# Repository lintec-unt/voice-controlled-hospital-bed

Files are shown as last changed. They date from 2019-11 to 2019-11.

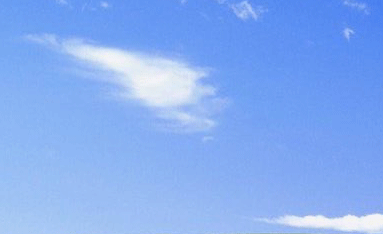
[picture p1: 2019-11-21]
PCSoftwareCode/Resources/FondoModificado_04.gif

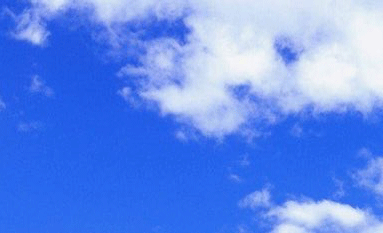
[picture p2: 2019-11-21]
PCSoftwareCode/Resources/FondoModificado_031.gif

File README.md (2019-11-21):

# Voice Controlled Hospital Bed System 1.0

This is the version 1.0 of the Voice Controlled Hospital Bed System. This proyect aims to allow bedridden patients that have a discapacity that do not allow them to use their hands to control the position of their bed, but they can talk, to control the bed with oral commands.

In this first version, the system can only work with a particular model of hospital bed (Pettinari PM Millennium), and it works with a PC with a speech recognition software (for example, Windows Speech Recognition, Dragon NaturallySpeaking, among others).

The system has the following parts:

* PC with Microsoft Windows OS and a speech recognition software.
* PC software to control the hospital bed.
* Arduino UNO board that translates the commands from the PC to actions in the bed.
* An Arduino shield that has all the extra hardware needed.
* A case to put the Arduino board and its shield to adapt it in the bed.

In this repository, we have uploaded the codes and files of:

* Code of the PC software to control the hospital bed.
* Code of the Arduino UNO board.
* PCB design of the Arduino shield.
* A STL file of the case.

### Arduino shield (PCB folder)

The arduino UNO board is connected to the hospital bed by the communication port for the wired remote control command. To emulate the buttons of the remote control, we used the GPIO port. As we intended to avoid electrical connection between the Arduino board (and the PC in upstream connection), the connections with the bed and the GPIO ports are between optocouplers. After the optocouplers, there is DIN connector (DIN 41524) that is connected in the bed. the connection between the PC and the Arduino board is by the means of the USB serial port.

The PCB design (the PCB folder) includes the optocouplers and a connector for the cable with the DIN connection.

### Arduino Board Software (ArduinoCode folder)

It was developed under Arduino IDE and with the standard libraries from Arduino.cc

This software has the typical infinite loop structure (setup() and loop()). In setup(), it starts all the GPIO pin needed as inputs and wait a command from the PC to start working. In loop(), the Arduino receive a char, and if it means a valid command, it activates the corresponding GPIO pin.

### The case (STL folder)

The arduino board and its shield was attached in the hospital bed by a 3d printed case. This case works as kind of protection for all the electronics.  

### The PC sofware (PCSoftwareCode folder)

The software that send the commands to the arduino is coded in C#, it was coded under Visual Studio IDE 15.

When the software is initializated, it search for the Arduino board in the differents avalaible serial ports (COM ports). To find it, it sends a char that the Arduino undestand as valid one and the Arduino responds with another char. The main windows has all the commands to move the bed in the form of images. If the user does a click in one of them, the software sends the correponding command to the Arduino to move the bed every 500 ms (this delta of time assures a smooth movement of the bed). To stop the movement, it is necesary to click in the same image but also, the software automatically stop the movement after 30 seconds.

The user using the speech recognition software can send a voice command to make click in one of the images. The size of the images are intended to make easier to the user to choose one of the images.

## Roadmap

For new advances in this work, we want to add the support for other models and brand of hospital beds. Also, we want adding the posibility to replace the PC with a embebbed system with a buit-in speech recognition software.

We are open to new ideas, everyone is open to participate in this development, as long as the guidelines are respected (see Contributing.md)

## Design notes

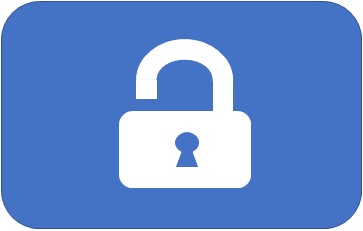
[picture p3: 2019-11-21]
PCSoftwareCode/Resources/az_desbloq.jpg

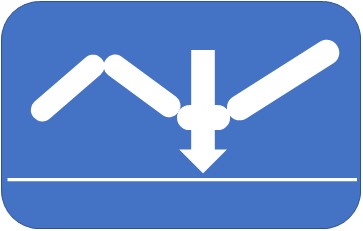
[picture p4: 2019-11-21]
PCSoftwareCode/Resources/az_cm_aba1.JPG

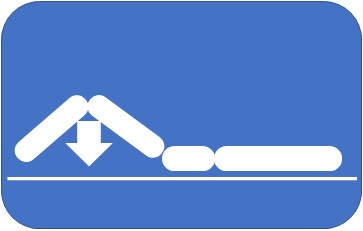
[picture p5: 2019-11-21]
PCSoftwareCode/Resources/az_pie_aba1.JPG

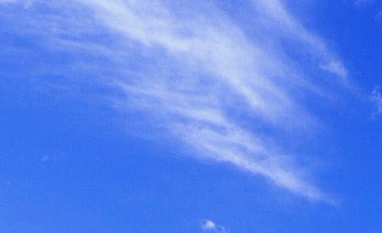
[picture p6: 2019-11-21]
PCSoftwareCode/Resources/FondoModificado_02.gif

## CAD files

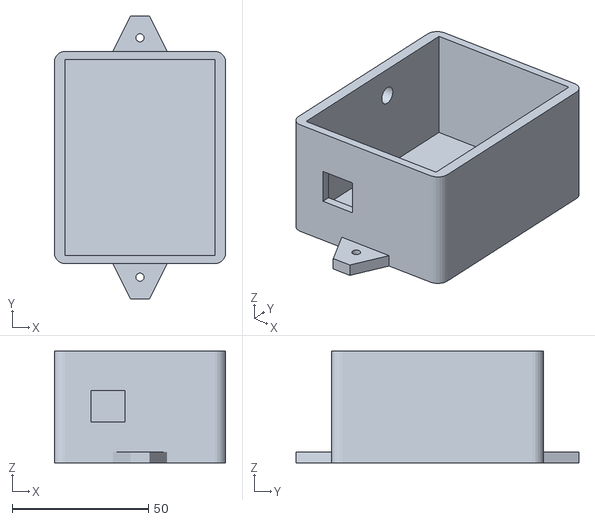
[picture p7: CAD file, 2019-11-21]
STLCase/ArduinoCase.stl
63.0 x 104.0 x 41.0

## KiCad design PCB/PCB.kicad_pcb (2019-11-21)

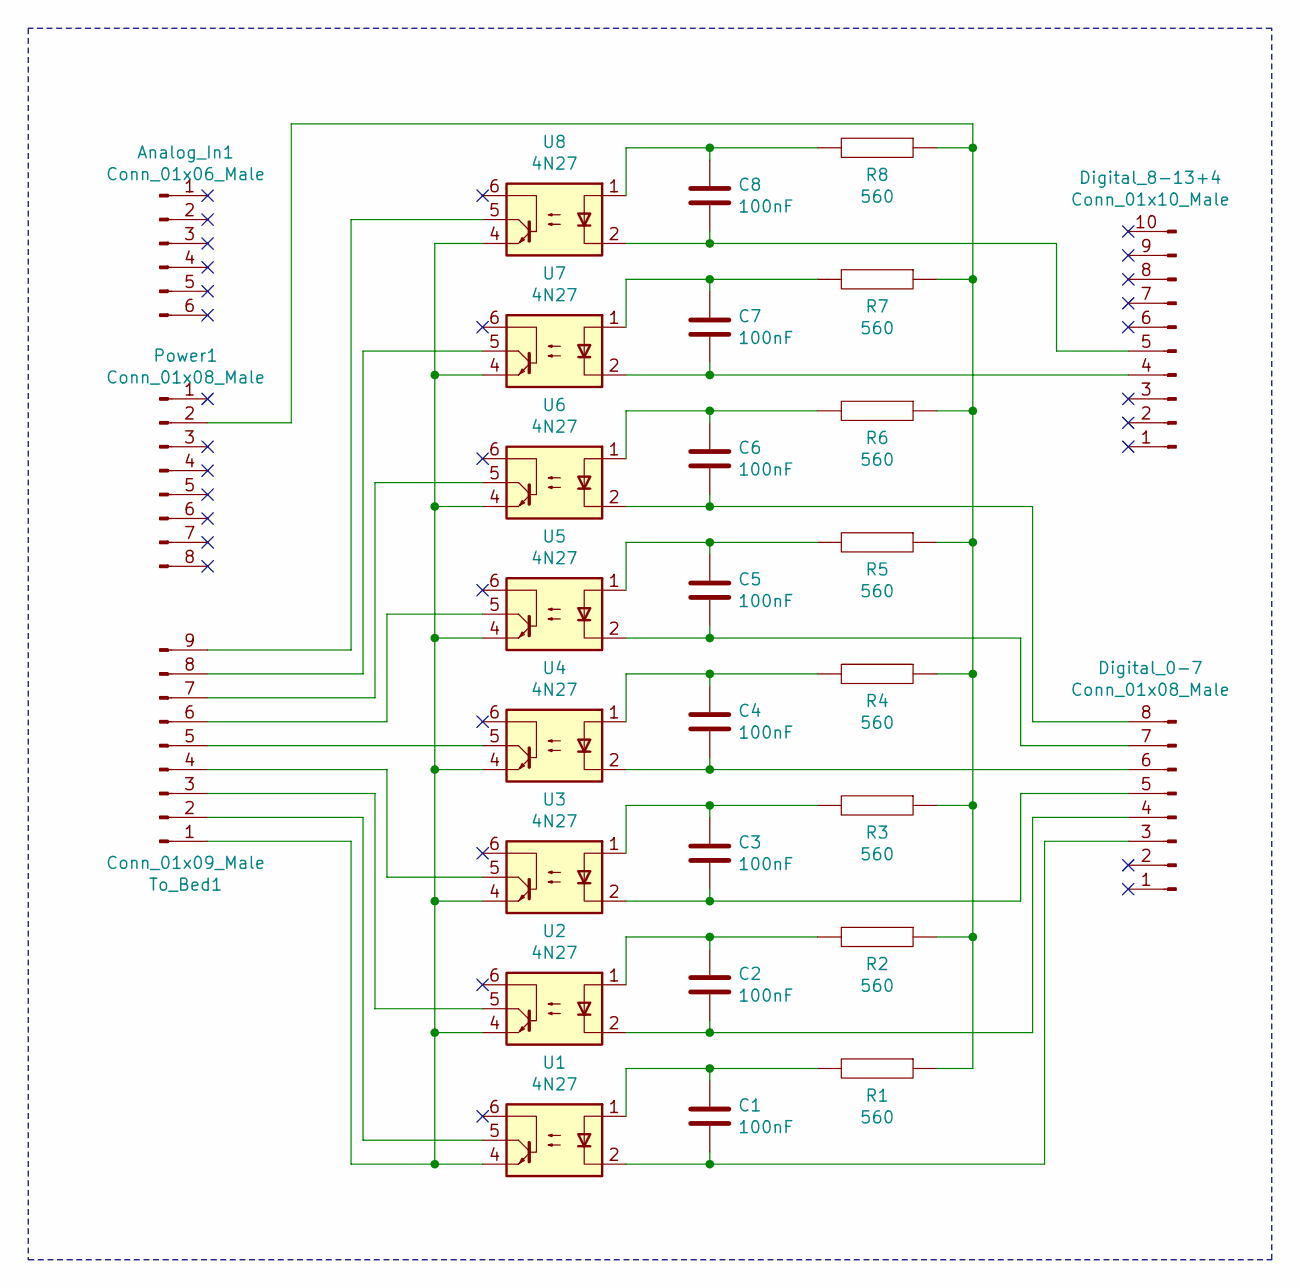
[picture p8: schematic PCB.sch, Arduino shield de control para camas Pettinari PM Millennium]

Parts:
Analog_In1: Conn_01x06_Male; PinHeader_1x06_P2.54mm_Vertical
C1, C2, C3, C4, C5, C6, C7, C8: 100nF; C_Disc_D6.0mm_W2.5mm_P5.00mm
Digital_0-7: Conn_01x08_Male; PinHeader_1x08_P2.54mm_Vertical
Digital_8-13+4: Conn_01x10_Male; PinHeader_1x10_P2.54mm_Vertical
Power1: Conn_01x08_Male; PinHeader_1x08_P2.54mm_Vertical
R1, R2, R3, R4, R5, R6, R7, R8: 560; R_Axial_DIN0207_L6.3mm_D2.5mm_P7.62mm_Horizontal
To_Bed1: Conn_01x09_Male; PinHeader_1x09_P2.54mm_Vertical
U1, U2, U3, U4, U5, U6, U7, U8: 4N27; DIP-6_W7.62mm

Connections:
unnamed: C1.1, R1.2, U1.1
unnamed: C1.2, Digital_0-7.3, U1.2
unnamed: C2.1, R2.2, U2.1
unnamed: C2.2, Digital_0-7.4, U2.2
unnamed: C3.1, R3.2, U3.1
unnamed: C3.2, Digital_0-7.5, U3.2
unnamed: C4.1, R4.2, U4.1
unnamed: C4.2, Digital_0-7.6, U4.2
unnamed: C5.1, R5.2, U5.1
unnamed: C5.2, Digital_0-7.7, U5.2
unnamed: C6.1, R6.2, U6.1
unnamed: C6.2, Digital_0-7.8, U6.2
unnamed: C7.1, R7.2, U7.1
unnamed: C7.2, Digital_8-13+4.4, U7.2
unnamed: C8.1, R8.2, U8.1
unnamed: C8.2, Digital_8-13+4.5, U8.2
unnamed: Power1.2, R1.1, R2.1, R3.1, R4.1, R5.1, R6.1, R7.1, R8.1
unnamed: To_Bed1.1, U1.4, U2.4, U3.4, U4.4, U5.4, U6.4, U7.4, U8.4
unnamed: To_Bed1.2, U1.5
unnamed: To_Bed1.3, U2.5
unnamed: To_Bed1.4, U3.5
unnamed: To_Bed1.5, U4.5
unnamed: To_Bed1.6, U5.5
unnamed: To_Bed1.7, U6.5
unnamed: To_Bed1.8, U7.5
unnamed: To_Bed1.9, U8.5

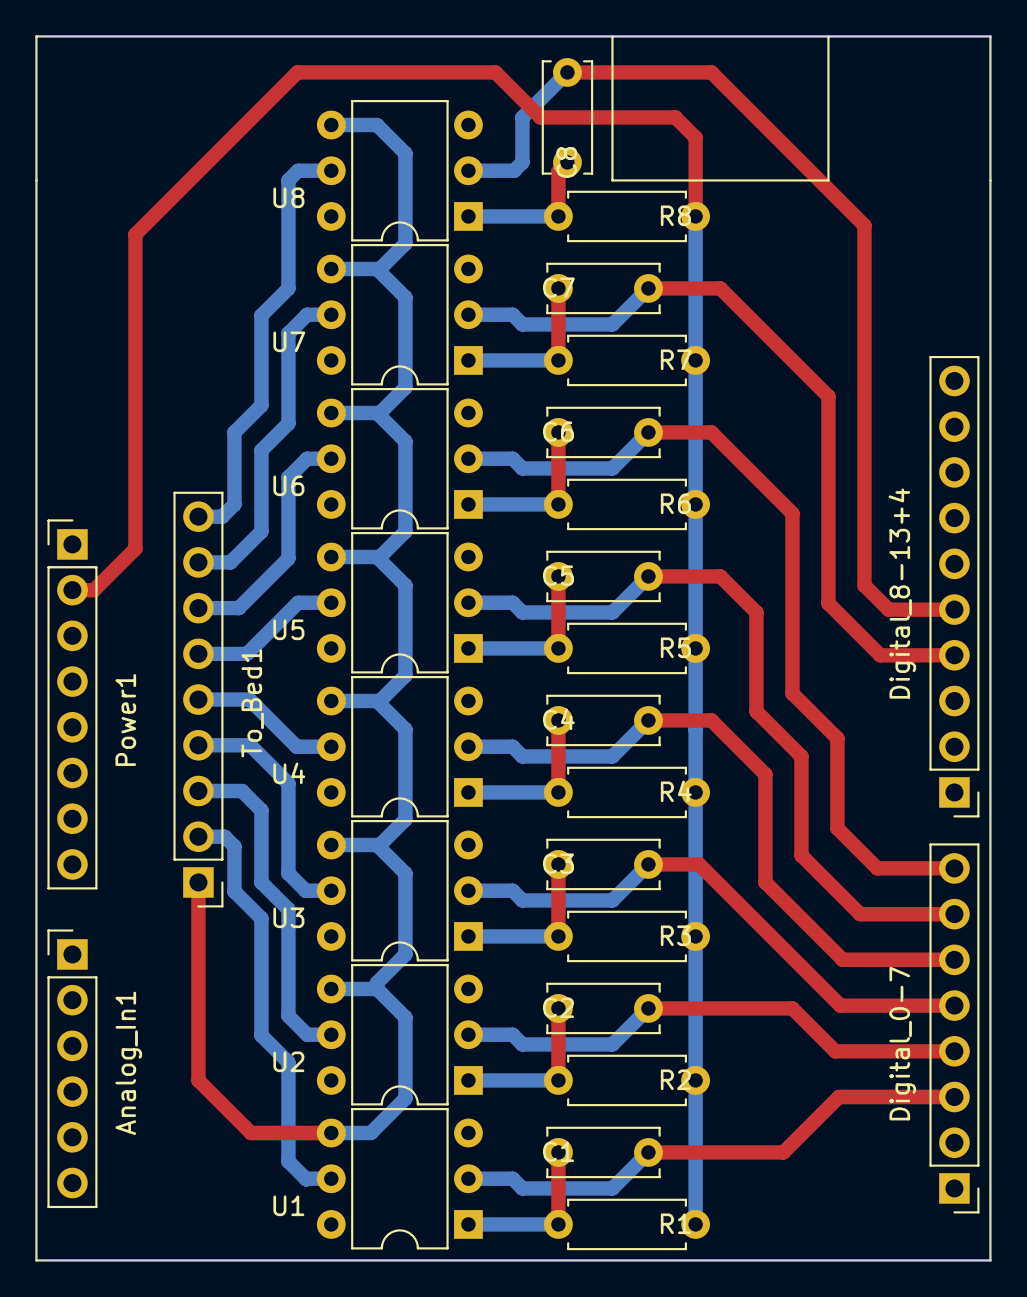
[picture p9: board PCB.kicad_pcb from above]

Board: 2 copper layers, 53.0 x 68.0 mm, 29 parts (0 on the bottom side), 26 nets.

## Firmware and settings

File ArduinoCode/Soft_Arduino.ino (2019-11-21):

/* Copyright (c) 2019, CONICET, UNT, SIPROSA
 * All rights reserved.
 *
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
 *
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
 *
 * 3. Neither the name of the copyright holder nor the names of its
 *    contributors may be used to endorse or promote products derived from
 *    this software without specific prior written permission.
 *
 *
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
 */

/* Author: Facundo Adrián Lucianna (flucianna@herrera.unt.edu.ar) */
/* Date (DD/MM/YYYY): 11/10/2018 */

/*==================[macros y definiciones]=================================*/

#define NPIN1  2     //Pin 2 Arduino
#define NPIN2  3     //Pin 3 Arduino
#define NPIN3  4     //Pin 4 Arduino
#define NPIN4  5     //Pin 5 Arduino
#define NPIN5  6     //Pin 6 Arduino
#define NPIN6  7     //Pin 7 Arduino
#define NPIN7  11    //Pin 11 Arduino
#define NPIN8  12    //Pin 12 Arduino

#define SERIALOKPC          99      //El caracter "c" en ASCII que envia la PC para conectar con el sistema
#define SERIALACKTOPC       10      //Se envia el numero 10 a la PC para avisarle que esta vivo.

#define SERIALPENADEL       51      //ASCII para pendulo adelante
#define SERIALPENATRAS      49      //ASCII para pendulo atras

#define SERIALPIEARRIBA     56      //ASCII para pie arriba
#define SERIALPIEABAJO      50      //ASCII para pie arriba

#define SERIALCABABAJO      52      //ASCII para cabeza abajo
#define SERIALCABARRIBA     55      //ASCII para cabeza arriba

#define SERIALCAMAABAJO     53      //ASCII para cama abajo
#define SERIALCAMAARRIBA    54      //ASCII para cama arriba

#define SERIALDESBLOQUEO    57      //Serial para desbloqueo

#define TIEMPOESPERACONF    250     //1/4 de segundo de espera
#define TIEMPOESPERASERIAL  500     //Medio segundo de espera
#define BAUDS               9600    //9600 baudios de transmision serial

/*==================[tipos de datos declarados por el usuario]===============*/
/*==================[declaraciones de datos externos]========================*/

int incomingByte = 0; // Variable que almacena lo que llega de la PC

bool flagSerial = false; // Flag para indicar que llego algo del puerto serie

/*==================[definiciones de funciones externas]=====================*/

/*-----------------------------------------------------------------
 *   La función setup() configura las salidas de los pines para
 *   controlar la cama y luego se configura el puerto serie y espera
 *   a la PC o sistema embebido que lo controla se comunique con el
 *   sistema.
 *-----------------------------------------------------------------*/
void setup()
{

  pinMode(NPIN1,OUTPUT);
  pinMode(NPIN2,OUTPUT);
  pinMode(NPIN3,OUTPUT);
  pinMode(NPIN4,OUTPUT);
  pinMode(NPIN5,OUTPUT);
  pinMode(NPIN6,OUTPUT);
  pinMode(NPIN7,OUTPUT);
  pinMode(NPIN8,OUTPUT);

  digitalWrite(NPIN1, HIGH);
  digitalWrite(NPIN2, HIGH);
  digitalWrite(NPIN3, HIGH);
  digitalWrite(NPIN4, HIGH);
  digitalWrite(NPIN5, HIGH);
  digitalWrite(NPIN6, HIGH);
  digitalWrite(NPIN7, HIGH);
  digitalWrite(NPIN8, HIGH);

  delay(TIEMPOESPERACONF);

  Serial.begin(BAUDS);
  //Serial.println("Test cama");   // DEBUG: Mensaje de bienvenida

  delay(TIEMPOESPERACONF);

  while(1) {
    if (Serial.available() > 0) { // Hay algo en el puerto serie

      incomingByte = Serial.read(); // Leemos el dato

      if (incomingByte == SERIALOKPC) {  // La PC intenta conectarse al Arduino

        Serial.print(SERIALACKTOPC, DEC);   // Confirmamos intento de conexión al software
        break;

      }
    }
  }
}

/*-----------------------------------------------------------------
 *   La función loop() realiza el bucle infinito en donde se recibe
 *   los caracteres de la PC y en funcion de cual sea, da un control
 *   a la cama.
 *-----------------------------------------------------------------*/
void loop()
{

  if (Serial.available() > 0) { // Hay algo en el puerto serie

    incomingByte = Serial.read(); // Leemos el dato

    //Esto es necesario si la PC se desconecta y vuelve a conectar y no se tenga que reiniciar el microcontrolador.
    if (incomingByte == SERIALOKPC) { // El software intenta conectarse al Arduino

      Serial.print(SERIALACKTOPC,DEC);// Confirmamos intento de conexión al software
      flagSerial = false;
    } else {

      flagSerial = true;
    }
  }

  if (flagSerial) {   // Esta flag esta para que solo cambie de estado los pines cuando se recibio algo del puerto serial.

    switch (incomingByte) {  // Dependiendo del valor de la variable, hacemos algo o no.
      case SERIALPENADEL:

        digitalWrite(NPIN1, LOW);
        digitalWrite(NPIN2,HIGH);
        digitalWrite(NPIN3,HIGH);
        digitalWrite(NPIN4,HIGH);
        digitalWrite(NPIN5,HIGH);
        digitalWrite(NPIN6,HIGH);
        digitalWrite(NPIN7,HIGH);
        digitalWrite(NPIN8,HIGH);
        flagSerial = false;
        break;
      case SERIALPIEABAJO:

        digitalWrite(NPIN1,HIGH);
        digitalWrite(NPIN2,LOW);
        digitalWrite(NPIN3,HIGH);
        digitalWrite(NPIN4,HIGH);
        digitalWrite(NPIN5,HIGH);
        digitalWrite(NPIN6,HIGH);
        digitalWrite(NPIN7,HIGH);
        digitalWrite(NPIN8,HIGH);

        flagSerial = false;
        break;
     case SERIALCABABAJO:

        digitalWrite(NPIN1,HIGH);
        digitalWrite(NPIN2,HIGH);
        digitalWrite(NPIN3,LOW);
        digitalWrite(NPIN4,HIGH);
        digitalWrite(NPIN5,HIGH);
        digitalWrite(NPIN6,HIGH);
        digitalWrite(NPIN7,HIGH);
        digitalWrite(NPIN8,HIGH);

        flagSerial = false;
        break;
     case SERIALCAMAABAJO:

        digitalWrite(NPIN1,HIGH);
        digitalWrite(NPIN2,HIGH);
        digitalWrite(NPIN3,HIGH);
        digitalWrite(NPIN4,LOW);
        digitalWrite(NPIN5,HIGH);
        digitalWrite(NPIN6,HIGH);
        digitalWrite(NPIN7,HIGH);
        digitalWrite(NPIN8,HIGH);

        flagSerial = false;
        break;
     case SERIALCABARRIBA:

        digitalWrite(NPIN1,HIGH);
        digitalWrite(NPIN2,HIGH);
        digitalWrite(NPIN3,HIGH);
        digitalWrite(NPIN4,HIGH);
        digitalWrite(NPIN5,LOW);
        digitalWrite(NPIN6,HIGH);
        digitalWrite(NPIN7,HIGH);
        digitalWrite(NPIN8,HIGH);

        flagSerial = false;
        break;
     case SERIALCAMAARRIBA:

        digitalWrite(NPIN1,HIGH);
        digitalWrite(NPIN2,HIGH);
        digitalWrite(NPIN3,HIGH);
        digitalWrite(NPIN4,HIGH);
        digitalWrite(NPIN5,HIGH);
        digitalWrite(NPIN6,LOW);
        digitalWrite(NPIN7,HIGH);
        digitalWrite(NPIN8,HIGH);

        flagSerial = false;
        break;
     case SERIALPIEARRIBA:

        digitalWrite(NPIN1,HIGH);
        digitalWrite(NPIN2,HIGH);
        digitalWrite(NPIN3,HIGH);
        digitalWrite(NPIN4,HIGH);
        digitalWrite(NPIN5,HIGH);
        digitalWrite(NPIN6,HIGH);
        digitalWrite(NPIN7,LOW);
        digitalWrite(NPIN8,HIGH);

        flagSerial = false;
        break;
     case SERIALPENATRAS:

        digitalWrite(NPIN1,HIGH);
        digitalWrite(NPIN2,HIGH);
        digitalWrite(NPIN3,HIGH);
        digitalWrite(NPIN4,HIGH);
        digitalWrite(NPIN5,HIGH);
        digitalWrite(NPIN6,HIGH);
        digitalWrite(NPIN7,HIGH);
        digitalWrite(NPIN8,LOW);

        flagSerial = false;
        break;
     case SERIALDESBLOQUEO:

        digitalWrite(NPIN1,HIGH);  //Se acciona sistema para desbloquear la cama.
        digitalWrite(NPIN2,HIGH);
        digitalWrite(NPIN3,HIGH);
        digitalWrite(NPIN4,LOW);
        digitalWrite(NPIN5,HIGH);
        digitalWrite(NPIN6,LOW);
        digitalWrite(NPIN7,HIGH);
        digitalWrite(NPIN8,HIGH);

        flagSerial = false;
        break;
    default:     // Cualquier otro valor que llega, apaga todo. Lo ideal es que se mande un cero, pero si por algun motivo hay algun error de comunicacion, lo mejor que se puede hacer es que la cama no se mueva
        digitalWrite(NPIN1,HIGH);
        digitalWrite(NPIN2,HIGH);
        digitalWrite(NPIN3,HIGH);
        digitalWrite(NPIN4,HIGH);
        digitalWrite(NPIN5,HIGH);
        digitalWrite(NPIN6,HIGH);
        digitalWrite(NPIN7,HIGH);
        digitalWrite(NPIN8,HIGH);

        flagSerial = false;
        break;
    }
  }

  delay(TIEMPOESPERASERIAL);  // Espera TIEMPOESPERASERIAL. Esto no significa que no se puede mandar un comando serial en menos de TIEMPOESPERASERIAL segundos, sino que los ejecuta cada TIEMPOESPERASERIAL segundos (El puerto serial tiene un stack que va a almacenando cada valor que llega).

}

/*==================[fin del archivo]========================================*/
